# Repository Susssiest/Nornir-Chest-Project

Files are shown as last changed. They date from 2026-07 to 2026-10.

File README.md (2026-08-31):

# Nornir Chest from God of War Ragnarök

Whole Project

This is a 3D printable replica model of the Nornir Chest from God of War Ragnarök. My final version uses a variety of electronics to simulate the way the chest works in the game. In God Of War, Nornir Chests are puzzles found throughout the map that use their environments to hide and disguise the activators, or seals. There are 4 types of seals, totem poles, braziers, bells, and viking statues. They each have different activation methods, and each are tied to different runes on the chest. When a seal is activated, the rune on it flashes and disappears, and the corrisponding rune on the chest does the same. I currently have two versions of the chest, a fully printable version, and a fully electronic version with seals.

## The Seals

**Brazier** - two 7 pixel WS2812B rings, reed switch. Printed gold, black, grey, and blue/transparent PLA. Uses the reed switch to detect the magnetic Blades of Chaos inserted into the coals, and the LED rings are used as a rune and embers in the fire. The coals are printed with low infill and fewer walls so light can shine through. 

**Totem Pole** - 3 dumb LEDs, rotary encoder. Printed in PLA wood, and blue/transparent PLA. The rotary encoder tracks the rotation of the pole. The pole is connected to a hollow cylinder with three different runes. As it rotates, three LEDs on the side of the pole light the correct rune.

**Bell** - 1 dumb LED, piezo switch. Printed in PLA wood, gold, and blue/transperent PLA. The piezo disk detects vibration when the bell is rung. A dedicated LED lights the rune.

## The Chest

The chest uses three 7 pixel WS2812B rings and a servo. The servos turn 90 degrees to lock/unlock the chest, and the LEDs cover the runes. It is hinged, and is printed in multiple parts to avoid changes between the gold, black, grey, and blue/transparent PLA. Any parts that would otherwise be glued are connected via pins.

## The Base

The rocky base is not only a cool base for the chest, it acts as a hub for the electronics. I made room for a breadboard for beginners (like me lol), an Arduino Nano, and a battery pack. All wires go through holes, and they will have some supports in them when you pull them out. I suggest using a paper clip to stick it in and push all of the supports out, it shouldn't be too hard.

## Printing

The chest uses 5 filaments, mostly Sunlu and Bambu Labs. I printed some parts with a 0.2 mm nozzle, such as the hinges, viking head, runes, etc, to preserve small details and improve the accuracy of the prints. I also changed the speed and infill on some parts, for example, the runes are printed in 100% infill grey to let light only through the rune hole, and not be visible through the plastic. I always used glue, and I used a cheap smooth PEI plate I found on amazon.

643023963-7ee1bbd4-a273-487c-8561-48d0f8c64b1f

### All Components 

- Arduino Nano (powered via USB-C)
- 4× WS2812B LED rings (7 LEDs each) – one in each chest rune slot, and 2 in brazier
- 2× Servos – lock the lid
- Rotary encoder – rotating totem
- Reed switch – brazier (detects magnetic Blades of Chaos)
- Piezo disk – tracks bell vibration
- 3× single LEDs – illuminate the runes on the totem
- 1× single LED – illuminates the rune on the bell
- 4× AA battery pack – powers all LEDs and servos

## Credits

- [Blades of Chaos fridge magnet](https://makerworld.com/en/models/3068479-blades-of-chaos-fridge-magnet#profileId-3454054) — Used as the magnetic Blades of Chaos inserted into the brazier. It is meant to be a fridge magnet.
- [Stone formation base](https://makerworld.com/en/models/2541501-stoneformation-15?from=search#profileId-2798135) — This is the rocky base I used. I modified it to have a central port for all the electronics and indents to connect the chest and three seals.
- [HW-040 module case housing enclosure](https://makerworld.com/en/models/1896813-hw-040-module-case-housing-enclosure?from=search#profileId-2032305) — This is the enclosure I used for the rotary encoder.
- [Print-in-PLAce hinge set](https://makerworld.com/en/models/791901-print-in-PLAce-hinge-set?from=search#profileId-730453) — This is the hinge I used. I modified it to have extruded pins and be much smaller.

## Updates

- Added a fully 3D-printable version.
- Will update firmware to fit physical chest wherever needed.

## Get .blend File Here
(I'm also a noob to github lol. I can't figure out how to upload large files.)

https://drive.google.com/file/d/1p0lWug-2twfeMgqFWuvS9LOxBlz-mlpI/view?usp=sharing

## Updated BOM

Screenshot 2026-08-14 at 5 10 53 PM

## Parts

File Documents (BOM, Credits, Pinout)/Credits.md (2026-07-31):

https://makerworld.com/en/models/3068479-blades-of-chaos-fridge-magnet#profileId-3454054
https://makerworld.com/en/models/2541501-stoneformation-15?from=search#profileId-2798135
https://makerworld.com/en/models/1896813-hw-040-module-case-housing-enclosure?from=search#profileId-2032305
https://makerworld.com/en/models/791901-print-in-place-hinge-set?from=search#profileId-730453

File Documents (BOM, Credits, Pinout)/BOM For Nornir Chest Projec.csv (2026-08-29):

Item | Part Number | Description | Quantity (PART) | LINK | Notes | Prices | Total
1 | WS2812B-7-Ring | LED Ring | 5 | https://www.amazon.com/WS2812B-Integrated-Raspberry-Polarity-Protection/dp/B0FGNKC7QQ | 7 Pixel Each Ring. | $12 | $83.50
2 | A000005 | Arduino Nano Microcontroller | 1 | https://www.aliexpress.us/item/3256809685516678.html?curPageLogUid=5CaHrG3ZhrdQ |  | $13
2 | 59065-1-T-02-A | Reed Switch | 10 | https://www.aliexpress.us/item/3256803956030642.html?curPageLogUid=Fa0oPe1vlgEd |  | $2
3 | MG90D | Servo | 5 | https://www.aliexpress.us/item/2255800716939287.html?curPageLogUid=Z3gKo8SFpI16 | 4 pieces option. | $6
4 | KY040 | Rotary Encoder | 3 | https://www.aliexpress.us/item/3256812271134656.html?curPageLogUid=7Kls8qCOYRya | KY040 option. | $2.50
5 | 7BB-27-4L0 | Piezo Disk Sensor | 5 | https://www.aliexpress.us/item/3256805787073974.html?curPageLogUid=UOmzm5xA3pMd | 15 mm option. | $2
6 | N/A | Dupont Wires | N/P | https://www.aliexpress.us/item/3256806568245944.html?curPageLogUid=wJJyPuHxCR1f | 20 cm version. | $5.50
7 | MB102 | Breadboard | 1 | https://www.aliexpress.us/item/3256811972226710.html?curPageLogUid=qMl6iwuxHHIW | Need single 830 specifically. | $1.50
8 | D4X2MM | Magnet. 4 * 2 mm | N/A | https://www.aliexpress.us/item/3256809888929805.html?curPageLogUid=4x1vSrh0W456 |  | $6.50
9 | BH3411 | 4X AA Battery Holder | 2 | https://www.aliexpress.us/item/3256812462544992.html?curPageLogUid=n0huZEXnUeKT | 4X specifically. | $5
10 | L-7113QWC-D | 5mm White LED Diffused | 2 | https://www.aliexpress.us/item/3256809511151659.html?curPageLogUid=VWfludxQW9P6 | Need white option. | $4.50
11 | BJ-1OHM-1M-OHM | Resistor Kit | N/P | https://www.aliexpress.us/item/3256811586219421.html?curPageLogUid=IHU8X6zPDTQ3 | One kit. | $6.50
12 | N/A | Grey Filament | 1 | amazon.com/Filament-Printer-Beginner-Friendly-Printing/dp/B0DSC31ZXD/ref=sr_1_5_sspa?crid=2LGGIC794LPAT&dib=eyJ2IjoiMSJ9.eQKZI1h0T-YOPtObhboWIG_RNktaH_b-Udad5mX24wETbbpMUZ0Z5rh0vpbh7rLSgEg74xWm6uLPm_tvbGXEeIPvTcr38zwNHxsZ0UfXm-5ssqrQTWvOXREL1hwJ3alvJFGURizV0MXGbAhyBEPxa8I0v3zYT4xV4xi6m-6oXPM5TpVuQRroFNL9HL_fHbDlJ9-K2ohU5GUG8rBIKBY_ql5ROyeisAdPtTaoMvq7F6o.t3D__7Jmp2Mq9nTA0LAzR9pZMdfqqCc6r-YQqvCba5g&dib_tag=se&keywords=grey+sunlu&qid=1786670732&sprefix=gr+sunlu%2Caps%2C349&sr=8-5-spons&sp_csd=d2lkZ2V0TmFtZT1zcF9tdGY&psc=1 | Need specific light grey color. | $16
 |  |  |  | NOTE: Some links do not include full quantity in one purchase. | NOTE: This is my first electronics project, so I need a lot of different parts that an experienced hobbiest would have already. This means electronics like jumper wires, breadboards, resistors, etc, are things that I need because I am new to using electronics and don't have any myself.

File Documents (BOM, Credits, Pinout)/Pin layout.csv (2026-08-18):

Nano Pin | Part | Component
D2 | Totem LED 1 | Rotating Totem
D3 | Totem LED 2 | Rotating Totem
D4 | Totem LED 3 | Rotating Totem
D5 | WS2812B LED Ring | Brazier
D6 | 3× WS2812B LED Rings | Chest
D7 | Rotary Encoder CLK | Rotating Totem
D8 | Rotary Encoder DT | Rotating Totem
D9 | Servo Left | Chest Lock
D10 | Servo Right | Chest Lock
D11 | Rotary Encoder SW (optional) | Rotating Totem
D12 | Reed Switch | Brazier
D13 | Bell LED | Bell
A0 | Piezo Disk | Bell

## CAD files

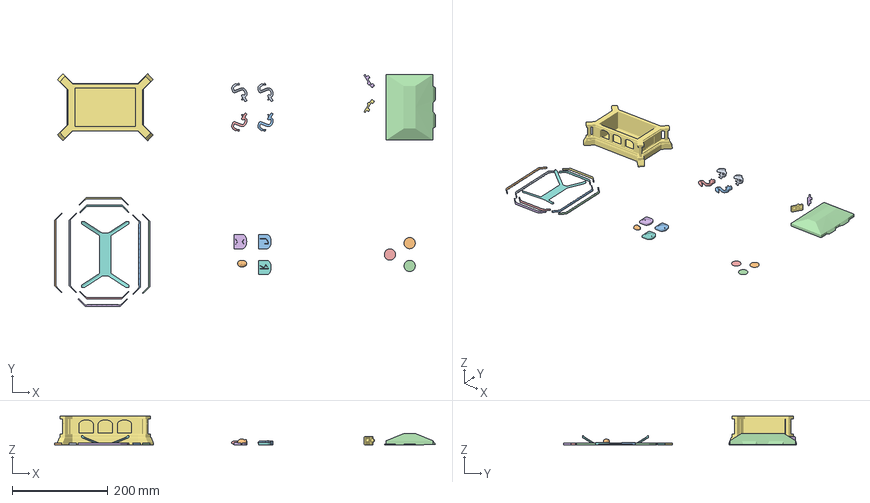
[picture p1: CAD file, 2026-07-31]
All CAD/Nornir Chest - Full 3D Print.3mf
794.8 x 485.2 x 60.0 mm
Corner_1.stl
Led_Cover_(C).stl
Rune_(N).stl
Led_Cover_(N).stl
Led_Cover_(R).stl
Rune_(C).stl
Main_Chest.stl
Rune_(R).stl
Corner_3.stl
Viking_Head.stl
Corner_2.stl
Lid.stl
Corner_4.stl
HINGE_1.stl
HINGE_2.stl
Gold_Engraving_(Lid).stl
Gold_Engraving_Long_1.stl
Gold_Engraving_Long_2.stl
Gold_Engraving_Long_3.stl
Gold_Engraving_Long_4.stl
Gold_Engraving_Short_1.stl
Gold_Engraving_Short_2.stl
Gold_Engraving_Short_3.stl
Gold_Engraving_Short_4.stl

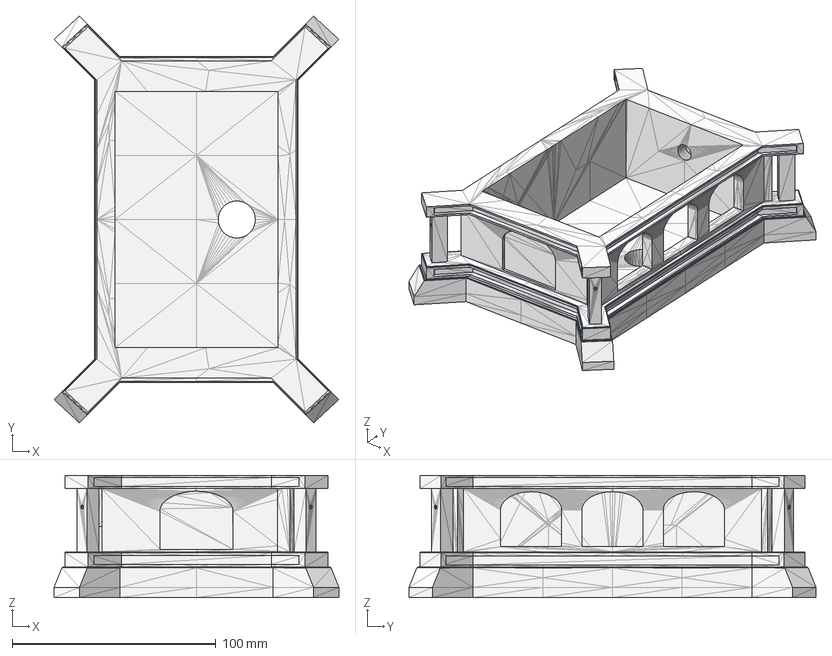
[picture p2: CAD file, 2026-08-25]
All CAD/All STEPS/Main_Chest - Arduino.step
140.0 x 200.0 x 60.0 mm

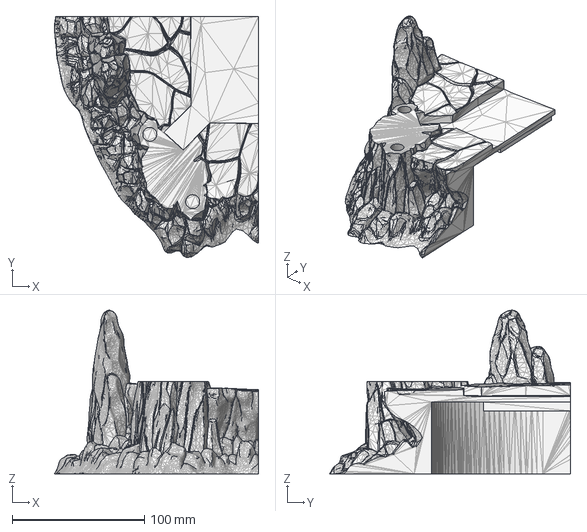
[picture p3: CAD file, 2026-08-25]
All CAD/All STEPS/Base_3.step
154.4 x 182.3 x 123.8 mm

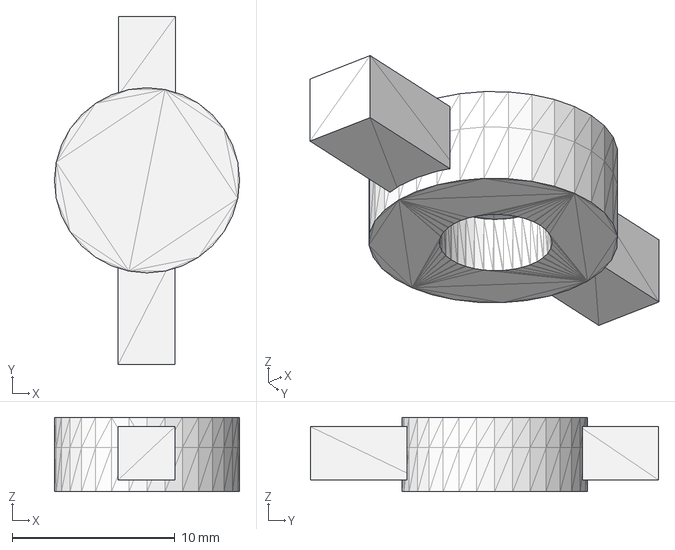
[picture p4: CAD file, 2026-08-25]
All CAD/All STEPS/Lock_2.step
11.4 x 21.4 x 4.58 mm

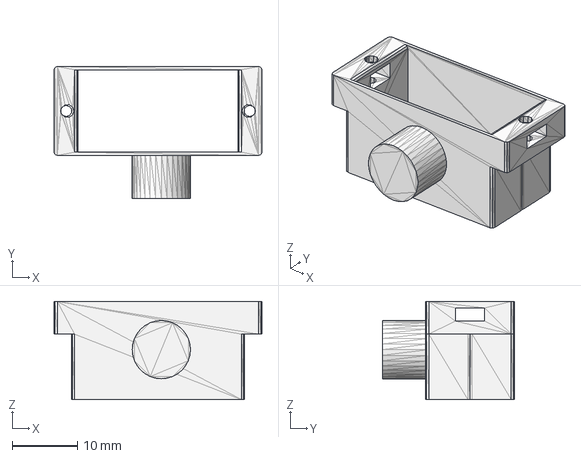
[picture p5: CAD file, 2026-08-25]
All CAD/All STEPS/Servo_Holder.step
31.8 x 20.2 x 15.0 mm

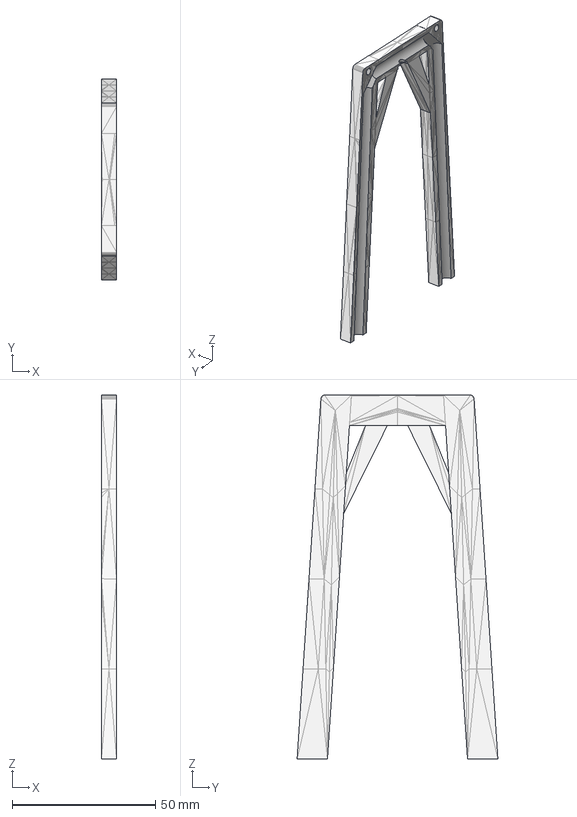
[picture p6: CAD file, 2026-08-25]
All CAD/All STEPS/Stand_1.step
5.31 x 70.1 x 127.0 mm

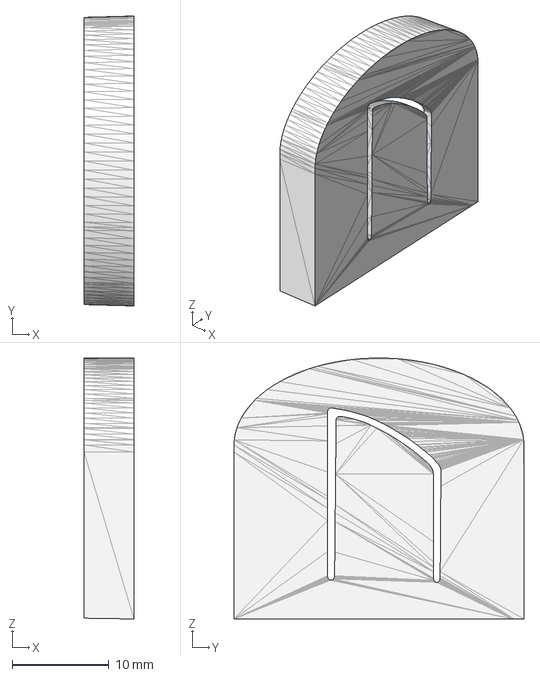
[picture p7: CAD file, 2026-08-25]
All CAD/All STEPS/Rune_(N).step
5.16 x 30.0 x 27.0 mm

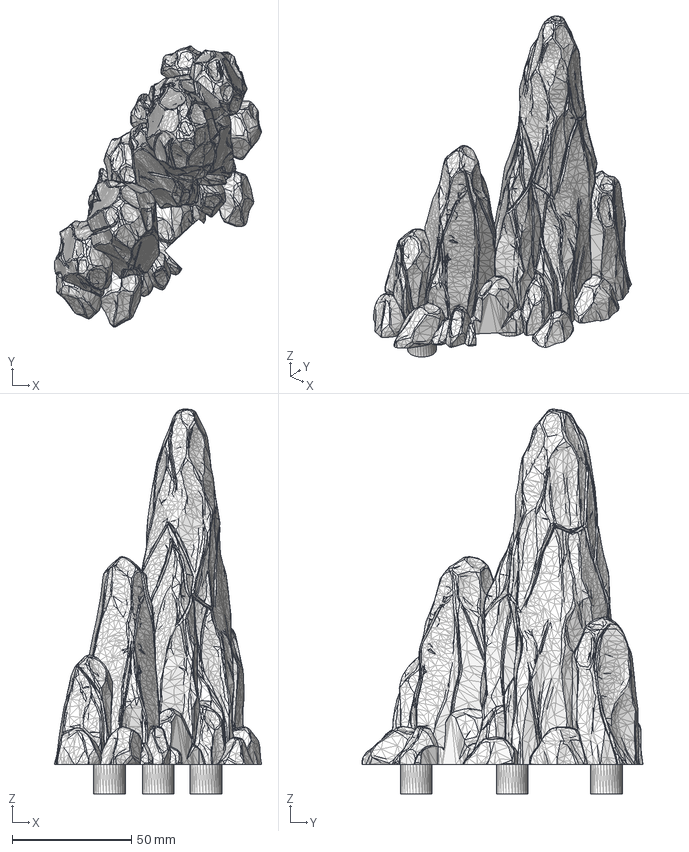
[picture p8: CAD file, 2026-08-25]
All CAD/All STEPS/Stalagmite_1.step
86.8 x 117.6 x 161.2 mm

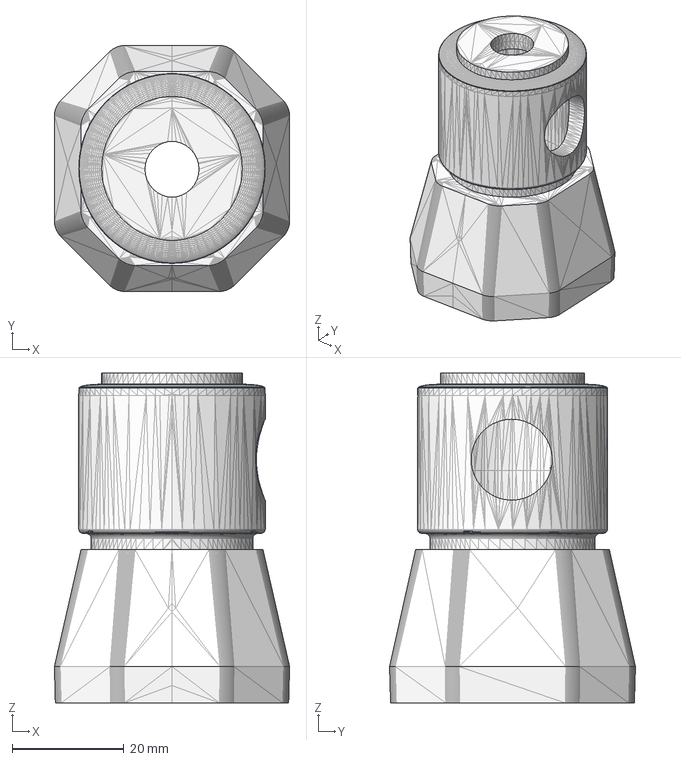
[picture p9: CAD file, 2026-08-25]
All CAD/All STEPS/Totem_Base.step
42.1 x 44.0 x 59.0 mm

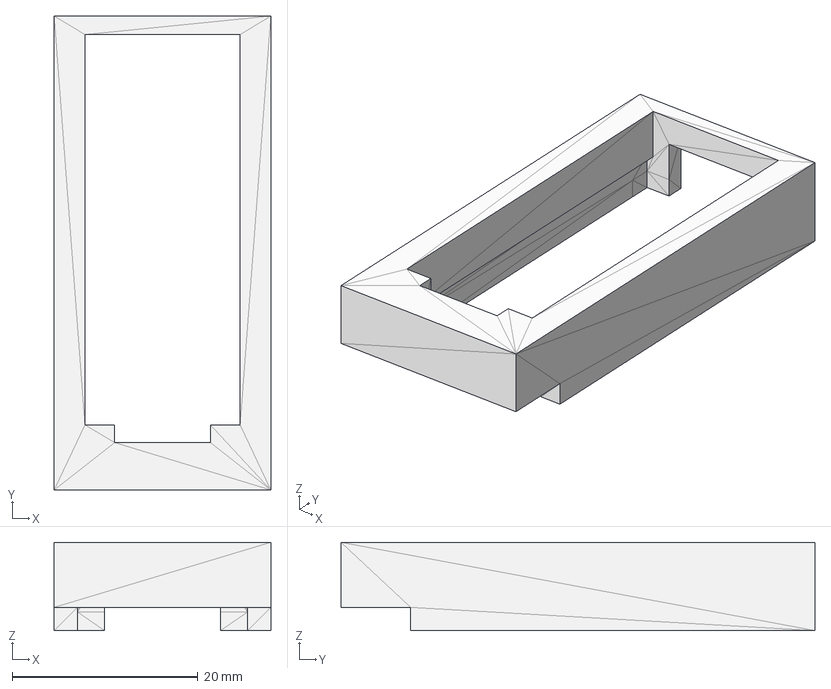
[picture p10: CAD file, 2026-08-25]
All CAD/All STEPS/Nano_Holder.step
23.3 x 51.0 x 9.51 mm

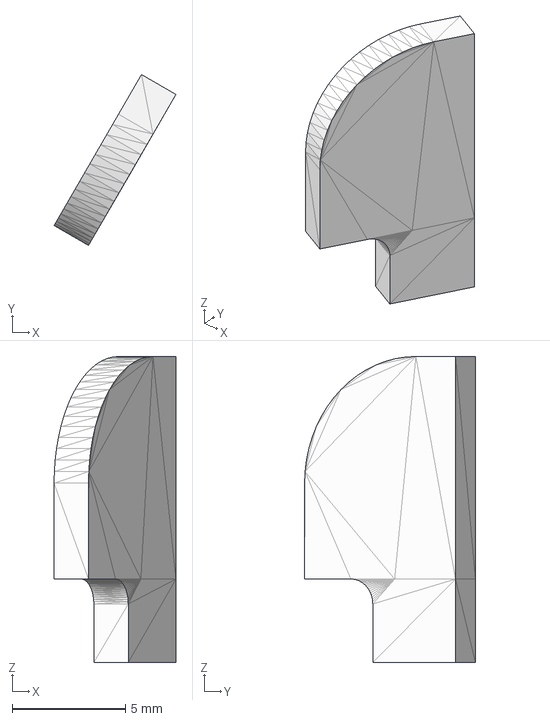
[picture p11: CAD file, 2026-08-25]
All CAD/All STEPS/Fin_PRINT_3.step
5.38 x 7.54 x 13.5 mm

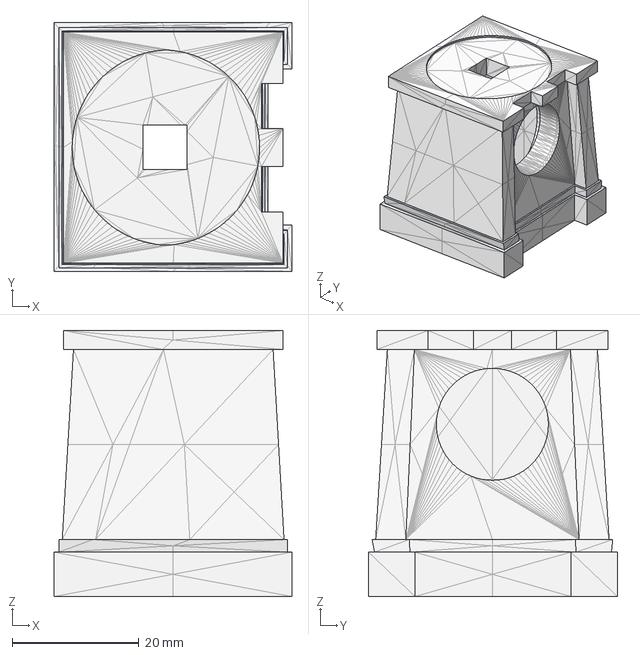
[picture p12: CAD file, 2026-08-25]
All CAD/All STEPS/Brazier_Base.step
37.5 x 39.3 x 42.0 mm

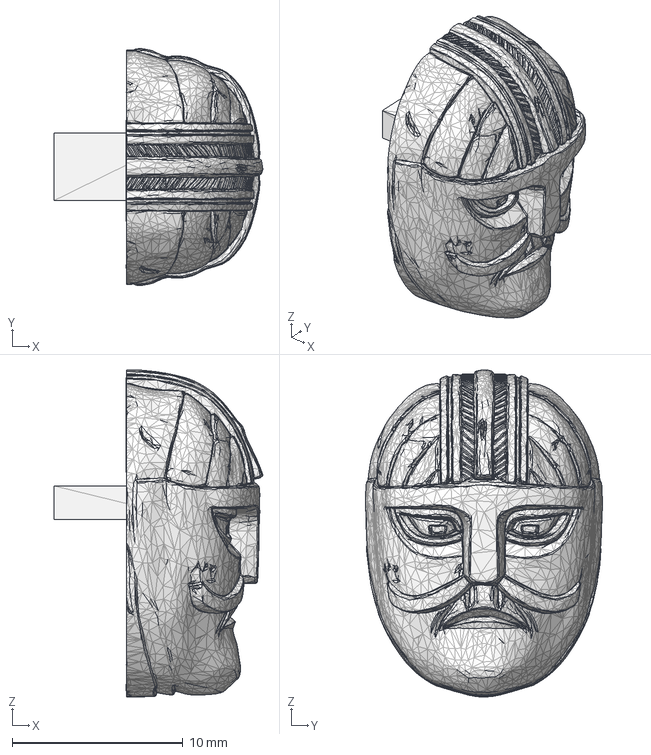
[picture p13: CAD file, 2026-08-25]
All CAD/All STEPS/Viking_Head.step
12.3 x 13.9 x 19.2 mm

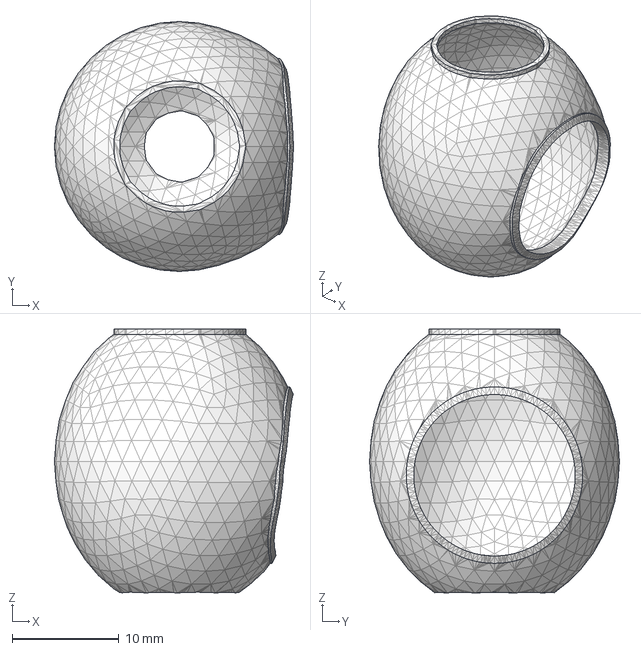
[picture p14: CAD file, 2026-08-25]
All CAD/All STEPS/Bell_Base.step
22.4 x 23.5 x 24.8 mm

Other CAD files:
All CAD/All STEPS/Servo_Holder_2.step
All CAD/All STEPS/Lock_1.step
All CAD/All STEPS/Stalagmite_2.step
All CAD/All STEPS/Rune_Cylinder.step
All CAD/All STEPS/Base_4.step
All CAD/All STEPS/Base_Cover.step
All CAD/All STEPS/Bell_Rune_(N).step
All CAD/All STEPS/Bell_Support.step
All CAD/All STEPS/Bottom.step
All CAD/All STEPS/Brazier_Rune_(R).step
All CAD/All STEPS/Brazier_Rune_Cover.step
All CAD/All STEPS/Electronics_Cover.step
All CAD/All STEPS/Gold_Engraving_(Lid).step
All CAD/All STEPS/Gold_Engraving_Long PRINT_4.step
All CAD/All STEPS/Hing_PRINT_2.step
All CAD/All STEPS/LED_Cover_(Totem_Pole).step
All CAD/All STEPS/Led_Cover_Print_3.step
All CAD/All STEPS/Lid.step
All CAD/All STEPS/Pole_Target Print_3.step
All CAD/All STEPS/Ring_Print_3.step
All CAD/All STEPS/Rune_(C).step
All CAD/All STEPS/Rune_(R).step
All CAD/All STEPS/Stand_Pin.step
All CAD/All STEPS/Totem_Pole.step

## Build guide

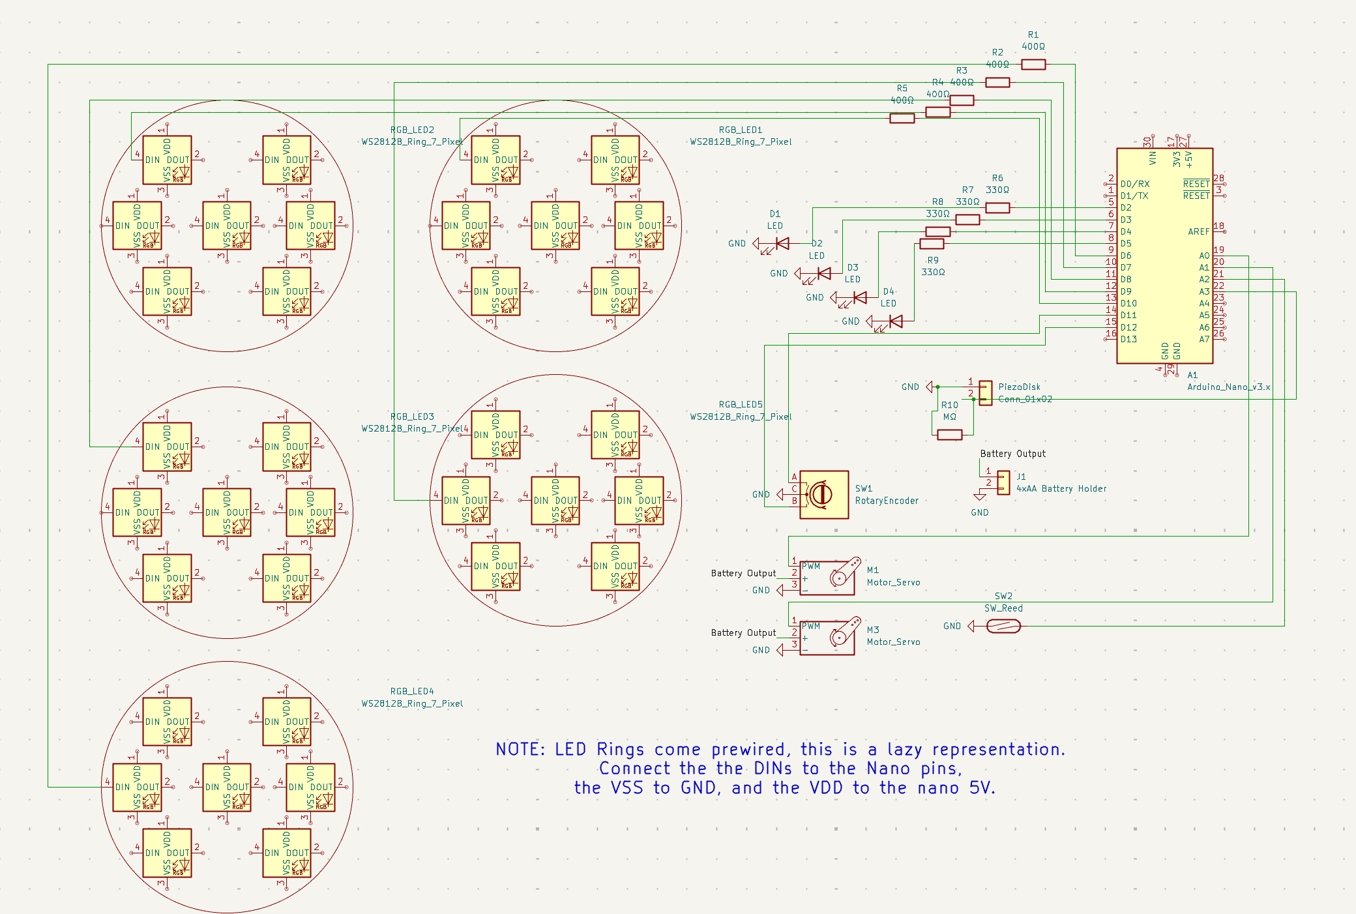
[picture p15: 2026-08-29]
Wiring Diagram.png

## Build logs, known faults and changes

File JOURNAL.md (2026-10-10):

# Journal

**PLEASE NOTE:**

- Project was moved from stardance to forge.
- I can't find actual dates I worked on projects, lapse gives me an estimate, like "3 months ago." for some reason, pretty annoying. The dates are estimations.
- This project was moved from stardance to forge, and the journals are just copied and pasted devlogs with some added details here and there.
- This was stardance, and I was a noob, so my devlogs are super short, and I switched between working on lots of different aspects of project, so I might log 2 hours 40 minutes and work for 40 minutes on the main thing and go over it in devlog, but spend another 2 hours polishing up a bunch of other stuff.
- I worked on this 3 months ago, I barely remember my workflow, I've tried to add a little more details, but pls be forgiving on awful devlogs.

## Worked on basic CAD on shell.

Started building my 3d printable Nornir Chest from God Of War. Just basic cadding, adding details like bevels, electronic holes, and runes later. Only cadded base chest, haven't started on lid or like hinges yet.



**Total time spent: 1h 25m**

## Worked on dragon corners 

Spent forever working on dragon corners, many revisions, restarted multiple times. Tried using cylinders, didn't work, tried using curves, kinda worked, eventually settled on a really low poly model because it prints tiny.



**Total time spent: 8h 32m**

## Added hinges and engravings

Added hinges and a gold engraving on the top of the lid. Looks great, moving on to head and leds for runes. Hinges print seperately and are inserted into pin holes, and are print in place, going to use 0.2mm nozzle because of how small they are. Gold engraving fits on the top and also is printed seperately.



**Total time spent: 1h 10m **

## Runes

Added runes! Looks great. Going to be using WS2812B Led rings, and I’m going to 3d print a cover thing for it that will disperse the lighting as it only has 7 leds per ring. 3 different runes, inserted into 3 different holes in chest.



**Total time spent: 2h 59m**

## Made MG90 Locking mechanism

It locks now! Will be using mg90 servos that turn 90 degrees, making the lid unable to open. Lid will have two holes on either sides with small covers that allow servo arm to fly over, but get stuck when lifted, because servo arm is in its way.



**Total time spent: 1h 47m**
 
## New gold engraving

Added a new gold engraving. It has kind of a loopy pattern, spent forever using curves to get it right, fits into holes in chest. Used multiple tutorials and I think I redid it maybe 4 times.



**Total time spent: 1h 31m**

## Made boulder and then gave up.

Spent some time making a boulder for the seals to sit on, but then I kind of gave up and realized it was ugly lol.



**Total time spent: 2h 47m**

## Chest base

The chest has a base now! The base is so big it has to split into fourths to fit on the printer bed 😂. It is ~700 grams. I also added indents in it that will fit a breadboard, battery pack, and wires. I’m going to be using a nano on the breadboard. I could just stuff all the electronics in the chest, but then i wouldnt be able to fir anything inside, so I’m just doing this. I also think it looks awesome and I need to add some of the puzzles that unlock the chest around it, so the base is perfect. Got the base off of makerworld - https://makerworld.com/en/models/2679972-rocky-base-plateau#profileId-2967898



**Total time spent: 4h 12m**
 
## Worked on brazier

I’m adding a little brazier with a led rune that will turn off when activated, and send a signal to the chest to also turn off one of the lights. Once three runes are activated the chest’s servos will activate and it will be able to open. Almost done with brazier, need to add some more coal on the top.



**Total time spent: 2.16 hours**
 
## Added reed switch

Added reed switch to brazier, I downloaded a nice blades of chaos fridge magnet, that can be inserted into the top. So hopefully when the magnetic blade gets inserted the reed switch will activate and send a signal to the arduino.



**Total time spent: 52m**
 
## CHose new base.

I’m choosing to use a different base, it just looks cooler, and also the other base had all these random strings of internal vertices. Also worked a little on the spinning rune activator/totem.



**Total time spent: 3h 38m**
 
## Finished brazier and totem.

Done with both brazier and spinning totem! On to rune rock and then wire paths and electronics.



**Total time spent: 46m**
 
## Finished everything.

Done with everything! I decided to do the bell instead of rune rock because I realized it wasn’t actually a rock, it was a statue, and I don’t want to spend 2 hours sculpting it. Prepping it in bambu studio, almost ready to start printing! Attached photo of statue to show you what I mean.



**Total time spent: 8h 30m**
 
## test print.

Printed base, supports are way to crazy and areas are too weak, tweaking and reprinting. Also starting to add some more work to the bambu studio portion of the project.



**Total time spent: 1h 13m**
 
## August 7th

Almost done with Bambu Studio. Putting together files for a fully 3d printable model too, no electronics, no base.



**Total time spent: 25m**
 
## Submitted for funding.

I’m submitting this for funding! I am broke and cant pay for the electronics lol. I also printed out a few parts. It needs a little post prosessing but looks great!

Screenshot 2026-09-15 at 4 40 39 PM

**Total time spent: 17m**
 
## Printed everything.

Finally printed all of the print only parts! Looks awesome. Still waiting on electronics.



**Total time spent: 19m**
 
## Posted on makerworld

Worked on firmware and updated BOM. also posted on makerworld! https://makerworld.com/en/models/3198743-god-of-war-nornir-chest-hinged-lid-no-ams#profileId-3619555



**Total time spent: 1h 4m**
 
## New lamp version.

Made a cheap lamp version using a kit from bambu labs, posted on makerworld. https://makerworld.com/en/models/3271930-god-of-war-nornir-chest-lamp-edition#profileId-3710162

Screenshot 2026-09-15 at 5 11 46 PM

**Total time spent: 1h 16m**

## Parts came

All parts came! Spent 2 minutes pulling in package i guess lol. Gonna start working on final build.

Screenshot 2026-09-15 at 5 18 21 PM

**Total time spent: 2m**

## More printing

Printed and removed all supports of 1/4 of the base. My stupid ass didn't record the first 5 minutes of support removal, and in the three visible frames I'm holding the base out of the cameras line of sight.

Screenshot 2026-09-16 at 4 24 35 PM

**Total time spent: 10m**

## Started working on arduino

Soldered on pin headers to the nano, dupont connectors to the battery holder, and looped all the leds.

Screenshot 2026-09-21 at 6 56 41 PM

**Total time spent: 1h 2m**

## Chest leds

Connected LEDs to nano, they work great. I'm really happy with how they came out. I'm going to work out the firmware to make it glow/ flicker blue. Also temporarily duct taped everything. I have settled on soldering everything together after I am out of the prototyping phase.

Screenshot 2026-09-22 at 10 12 33 AM

**Total time spent: 30 m**

## Servos dont fit in lid.

Tested servos, current lid locking system is really bad, servo arm doesnt even fit in the space I made for it. Changed lid to have an extruding handle thing that will be blocked by servo arms. 

Screenshot 2026-10-04 at 5 19 23 PM

**Total time spent: 1 hour**

## Fixed servos, work good.

Printed out new parts, replaced them, and tested. I had a pretty easy time printing everything, took out old servo holders and added new ones. The lid did kind of lock, but I was able to lift the lid up maybe two centimeters. Decreased the tolerance in the lid handle things by wrapping duct tape around it. Added switch to open and close servos and uploaded new testing code. It works! I'm actually really happy with how it came out! Will start testing brazier tommorow.

Pi7_GIF_CMP-ezgif com-crop

**Total time spent: 2 hour**

## Totem pole leds

Spent like 3 hours trying to solder wire to a tiny led strip. Accidentally bought 2.5mm instead of 5mm. I wasted like 30 mm of wire. The strip has an adhesive on the bottom that prevents solder to sticking on pads so I ended up just covering the led strip with burnt glue and solder without actually making any connections. The diode leds i ordered dont work as well, they all came with messed up internals, I can see the metal parts inside are way too close togther.

Screenshot 2026-10-03 at 9 10 33 AM

**Total time spent: 3 hours**

## More work on totem pole leds

I took a portion of a bigger led strip from school because the one I own is way too hard to solder. I accidentally soldered the wires onto the DOUT side, and after 40 minutes of playing with arduino ide and switching between micrcontrollers, I finally decided to check the soldering a little closer, and realized I had soldered it on wrong. So I soldered it on correctly, and tested the leds, and they worked. Then I stuffed it into the pole and broke it accidentally. And then I decided to just gave up for the day for some reason.

Screenshot 2026-10-03 at 9 11 07 AM

**Total time spent: 2 hours**

## Finally got leds to work.

Soldered everything corectly this time, took maybe 30 minutes including setup and putting everything away. Made basic firmware to test if the rotary encoders work, and they do, it looks great. Spent forever trying to protect the wires against touching using tape, and connecting the rotary encoder to the breadboard, but it works! Leds flash red when not correct rune, leds flash white when correct. For some reason the leds stopped working and then after 30 minutes of panicking hey started working again, so I guess they work?

Screenshot 2026-10-04 at 4 39 45 PM

**Total time spent: 4 hours**

## Uh, i want to keep my forge streak.

I'm logging the five minutes it took to setup my printer and send a print because I want to keep my forge streak. Yeah.

Screenshot 2026-10-05 at 12 59 30 PM

**Total time spent: 5 minutes**

## Broke the last 3 led rings while soldering.

I spent over three hours trying to solder the wires pointing up horizontally, and ended up breaking every LED. The first leds pad fell off, the second ones' whole vcc trace and pad fell off, and the last led looked soldered ok, but when I plugged it into the nano it started smoking for some reason, so I took it out, and now the nano doesn't work. Luckily I bought a second one, so I had to replace it and solder all the pins on. I'm going to try to fix the last led, but worst case scenario I'll just use a cut off portion from a led strip.

**Total time spent: 4 hours**

## Soldered the reed switch to some dupont pins.

Luckily soldering the reed switch wasn't too hard, tested with a led and it works great. Now I'm going to stop ignoring soldering the leds and do it.

Screenshot 2026-10-08 at 8 25 48 PM

**Total time spent: 40 minutes**

## Got the last LED ring to work somehow

I resoldered everything, and now it works! Tested it, moving on to code and implementation.

Screenshot 2026-10-08 at 8 24 05 PM

**Total time spent: 1 hour**

## Hooked up leds and reed switch to nano, it works!

Connected everything to dupont pins and then the nano, and coded the reed switch part, it works! Blinks like the totem when activated. I am experiencing a problem where the rotary encoder automatically thinks it is on F when starting, going to fix.

Screenshot 2026-10-09 at 7 35 35 PM

**Total time spent: 1 hour 20 minutes**

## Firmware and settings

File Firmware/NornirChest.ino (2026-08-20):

#include "arduino_secrets.h"

#include <Adafruit_NeoPixel.h>
#include <Servo.h>

// ============================================================
// Pin assignments
// ============================================================

const byte TOTEM_LED_1_PIN = 2;
const byte TOTEM_LED_2_PIN = 3;
const byte TOTEM_LED_3_PIN = 4;

const byte BRAZIER_RING_PIN = 5;
const byte CHEST_RINGS_PIN  = 6;

const byte ENCODER_CLK_PIN = 7;
const byte ENCODER_DT_PIN  = 8;

const byte LEFT_SERVO_PIN  = 9;
const byte RIGHT_SERVO_PIN = 10;

const byte REED_SWITCH_PIN = 12;
const byte BELL_LED_PIN    = 13;
const byte PIEZO_PIN       = A0;

// D11 is not used.
// The rotary encoder switch is intentionally disconnected.

// ============================================================
// LED settings
// ============================================================

const byte CHEST_RING_COUNT = 3;
const byte PIXELS_PER_RING = 7;
const byte CHEST_PIXEL_COUNT = CHEST_RING_COUNT * PIXELS_PER_RING;

// Set this to 7 if you have one brazier ring.
// Set it to 14 if two brazier rings are chained together.
const byte BRAZIER_PIXEL_COUNT = 14;

const byte LED_BRIGHTNESS = 80;

Adafruit_NeoPixel chestPixels(
  CHEST_PIXEL_COUNT,
  CHEST_RINGS_PIN,
  NEO_GRB + NEO_KHZ800
);

Adafruit_NeoPixel brazierPixels(
  BRAZIER_PIXEL_COUNT,
  BRAZIER_RING_PIN,
  NEO_GRB + NEO_KHZ800
);

// ============================================================
// Servo settings
// ============================================================

Servo leftServo;
Servo rightServo;

// Adjust these angles for your physical lock mechanism.
const int LEFT_LOCKED_ANGLE   = 20;
const int LEFT_UNLOCKED_ANGLE = 110;

const int RIGHT_LOCKED_ANGLE   = 160;
const int RIGHT_UNLOCKED_ANGLE = 70;

// ============================================================
// Rotary encoder settings
// ============================================================

// Change this if your encoder has a different number of detents.
const int ENCODER_DETENTS_PER_REVOLUTION = 20;

// The three rune positions around the totem.
const int RUNE_ANGLES[] = {
  0,
  120,
  240
};

const byte NUMBER_OF_RUNES = 3;

// A rune is accepted within 5 degrees of its target angle.
const int ANGLE_CLEARANCE = 5;

int lastCLKState = HIGH;
long encoderDetents = 0;
bool encoderHasMoved = false;

// ============================================================
// Bell settings
// ============================================================

const int PIEZO_THRESHOLD = 180;
const unsigned long BELL_COOLDOWN_MS = 700;

unsigned long lastBellTrigger = 0;

// ============================================================
// Game state
// ============================================================

bool brazierSolved = false;
bool bellSolved = false;
bool totemSolved = false;
bool chestUnlocked = false;

// ============================================================
// Colors
// ============================================================

uint32_t lockedRuneColor;
uint32_t brazierActiveColor;
uint32_t flashColor;
uint32_t offColor;

// ============================================================
// Setup
// ============================================================

void setup() {
  Serial.begin(9600);

  // Ordinary LEDs
  pinMode(TOTEM_LED_1_PIN, OUTPUT);
  pinMode(TOTEM_LED_2_PIN, OUTPUT);
  pinMode(TOTEM_LED_3_PIN, OUTPUT);
  pinMode(BELL_LED_PIN, OUTPUT);

  // Rotary encoder
  pinMode(ENCODER_CLK_PIN, INPUT_PULLUP);
  pinMode(ENCODER_DT_PIN, INPUT_PULLUP);

  // Reed switch
  // The reed switch should connect D12 to GND when activated.
  pinMode(REED_SWITCH_PIN, INPUT_PULLUP);

  // Start encoder reading
  lastCLKState = digitalRead(ENCODER_CLK_PIN);

  // Initialize NeoPixels
  chestPixels.begin();
  brazierPixels.begin();

  chestPixels.setBrightness(LED_BRIGHTNESS);
  brazierPixels.setBrightness(LED_BRIGHTNESS);

  lockedRuneColor = chestPixels.Color(255, 70, 0);
  brazierActiveColor = brazierPixels.Color(255, 0, 0);
  flashColor = chestPixels.Color(255, 255, 255);
  offColor = chestPixels.Color(0, 0, 0);

  // Initialize servos
  leftServo.attach(LEFT_SERVO_PIN);
  rightServo.attach(RIGHT_SERVO_PIN);

  lockChest();

  clearBrazier();
  updateTotemLEDs(-1);
  updateChestRunes();

  Serial.println(F("Nornir Chest ready."));
  Serial.println(F("Solve the brazier, bell, and rotating totem."));
}

// ============================================================
// Main loop
// ============================================================

void loop() {
  if (chestUnlocked) {
    return;
  }

  checkBrazier();
  checkBell();
  checkTotem();

  if (brazierSolved && bellSolved && totemSolved) {
    unlockChest();
  }
}

// ============================================================
// Brazier
// ============================================================

void checkBrazier() {
  bool magnetDetected = digitalRead(REED_SWITCH_PIN) == LOW;

  if (magnetDetected && !brazierSolved) {
    brazierSolved = true;

    Serial.println(F("Brazier solved."));

    setAllBrazierPixels(brazierActiveColor);
    completeSeal(0);
  }
}

// ============================================================
// Bell
// ============================================================

void checkBell() {
  if (bellSolved) {
    return;
  }

  int piezoValue = analogRead(PIEZO_PIN);

  if (piezoValue >= PIEZO_THRESHOLD &&
      millis() - lastBellTrigger >= BELL_COOLDOWN_MS) {

    lastBellTrigger = millis();
    bellSolved = true;

    Serial.print(F("Bell solved. Piezo value: "));
    Serial.println(piezoValue);

    digitalWrite(BELL_LED_PIN, HIGH);
    completeSeal(1);
  }
}

// ============================================================
// Rotary encoder
// ============================================================

void checkTotem() {
  int currentCLKState = digitalRead(ENCODER_CLK_PIN);

  // Read one edge of the encoder's CLK signal.
  if (currentCLKState != lastCLKState && currentCLKState == LOW) {
    if (digitalRead(ENCODER_DT_PIN) != currentCLKState) {
      encoderDetents++;
    } else {
      encoderDetents--;
    }

    encoderDetents = wrapEncoderPosition(encoderDetents);
    encoderHasMoved = true;

    int currentAngle = getEncoderAngle();
    int selectedRune = findMatchingRune(currentAngle);

    Serial.print(F("Totem angle: "));
    Serial.print(currentAngle);
    Serial.print(F(" degrees, selected rune: "));
    Serial.println(selectedRune);

    updateTotemLEDs(selectedRune);

    // Require the user to rotate the totem at least once.
    // This prevents the chest from solving immediately at startup.
    if (encoderHasMoved && selectedRune >= 0 && !totemSolved) {
      totemSolved = true;

      Serial.println(F("Totem solved."));
      completeSeal(2);
    }
  }

  lastCLKState = currentCLKState;
}

long wrapEncoderPosition(long position) {
  while (position >= ENCODER_DETENTS_PER_REVOLUTION) {
    position -= ENCODER_DETENTS_PER_REVOLUTION;
  }

  while (position < 0) {
    position += ENCODER_DETENTS_PER_REVOLUTION;
  }

  return position;
}

int getEncoderAngle() {
  long angle = encoderDetents * 360L;
  angle /= ENCODER_DETENTS_PER_REVOLUTION;

  return angle;
}

int getAngleDifference(int firstAngle, int secondAngle) {
  int difference = abs(firstAngle - secondAngle);

  // Correctly handles the wraparound between 359 and 0 degrees.
  if (difference > 180) {
    difference = 360 - difference;
  }

  return difference;
}

int findMatchingRune(int currentAngle) {
  for (byte i = 0; i < NUMBER_OF_RUNES; i++) {
    int difference = getAngleDifference(
      currentAngle,
      RUNE_ANGLES[i]
    );

    if (difference <= ANGLE_CLEARANCE) {
      return i;
    }
  }

  return -1;
}

void updateTotemLEDs(int selectedRune) {
  digitalWrite(
    TOTEM_LED_1_PIN,
    selectedRune == 0 ? HIGH : LOW
  );

  digitalWrite(
    TOTEM_LED_2_PIN,
    selectedRune == 1 ? HIGH : LOW
  );

  digitalWrite(
    TOTEM_LED_3_PIN,
    selectedRune == 2 ? HIGH : LOW
  );
}

// ============================================================
// Chest rune LEDs
// ============================================================

void updateChestRunes() {
  setChestRing(
    0,
    brazierSolved ? offColor : lockedRuneColor
  );

  setChestRing(
    1,
    bellSolved ? offColor : lockedRuneColor
  );

  setChestRing(
    2,
    totemSolved ? offColor : lockedRuneColor
  );

  chestPixels.show();
}

void setChestRing(byte ringNumber, uint32_t color) {
  int firstPixel = ringNumber * PIXELS_PER_RING;

  for (byte i = 0; i < PIXELS_PER_RING; i++) {
    chestPixels.setPixelColor(firstPixel + i, color);
  }
}

void flashChestRing(
  byte ringNumber,
  byte numberOfFlashes,
  int delayTime
) {
  for (byte flash = 0; flash < numberOfFlashes; flash++) {
    setChestRing(ringNumber, flashColor);
    chestPixels.show();
    delay(delayTime);

    setChestRing(ringNumber, offColor);
    chestPixels.show();
    delay(delayTime);
  }
}

void completeSeal(byte ringNumber) {
  flashChestRing(ringNumber, 3, 130);
  setChestRing(ringNumber, offColor);
  chestPixels.show();
}

// ============================================================
// Brazier LEDs
// ============================================================

void setAllBrazierPixels(uint32_t color) {
  for (byte i = 0; i < BRAZIER_PIXEL_COUNT; i++) {
    brazierPixels.setPixelColor(i, color);
  }

  brazierPixels.show();
}

void clearBrazier() {
  setAllBrazierPixels(offColor);
}

// ============================================================
// Servos and chest lock
// ============================================================

void lockChest() {
  leftServo.write(LEFT_LOCKED_ANGLE);
  rightServo.write(RIGHT_LOCKED_ANGLE);

  Serial.println(F("Chest locked."));
}

void unlockChest() {
  chestUnlocked = true;

  Serial.println(F("All seals solved."));
  Serial.println(F("Unlocking chest."));

  // Celebration flash
  for (byte flash = 0; flash < 3; flash++) {
    for (int i = 0; i < CHEST_PIXEL_COUNT; i++) {
      chestPixels.setPixelColor(i, flashColor);
    }

    chestPixels.show();
    delay(180);

    for (int i = 0; i < CHEST_PIXEL_COUNT; i++) {
      chestPixels.setPixelColor(i, offColor);
    }

    chestPixels.show();
    delay(180);
  }

  // Move the locks to the open position.
  leftServo.write(LEFT_UNLOCKED_ANGLE);
  rightServo.write(RIGHT_UNLOCKED_ANGLE);

  // Leave the brazier lit.
  setAllBrazierPixels(brazierActiveColor);

  // Leave all totem and bell LEDs lit.
  digitalWrite(TOTEM_LED_1_PIN, HIGH);
  digitalWrite(TOTEM_LED_2_PIN, HIGH);
  digitalWrite(TOTEM_LED_3_PIN, HIGH);
  digitalWrite(BELL_LED_PIN, HIGH);
}

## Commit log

2026-07-31 Rename Nornir Chest - Arduino.3mf to Chest - Arduino.3mf
    [Chest - Arduino.3mf]
2026-07-31 Rename Chest - Arduino.3mf to Nornir Chest - Arduino.3mf
    [Nornir Chest - Arduino.3mf]
2026-07-31 Rename All Chest (Arduino) STLs.zip to Chest - Arduino STLs.zip
2026-07-31 Update README with new 3D printable version
    Added a note about the fully 3D printable version of the model.
2026-07-31 Add new model link for print-in-place hinge set
2026-08-03 Enhance README with electronics details and updates
    Expanded the README to include details about the electronics used in the Nornir Chest project, including descriptions of the seals and components. Added credits for resources and an update about a fu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
2026-08-03 Add documentation for Nornir Chest project
    Added detailed documentation for the Nornir Chest project, including project overview, electronics, pin assignments, wiring diagram, and power connections.
2026-08-03 Rename Wiring Diagram.readme to Wiring Diagram.md
2026-08-03 Update Wiring Diagram.md
2026-08-03 Revise Piezo disk description and add LED details
    Updated the description of the Piezo disk and added details about an additional LED ring in the brazier.
2026-08-03 Revise wiring diagram and power connection details
    Updated wiring diagram with detailed component connections and power notes.
2026-08-14 Update README to remove note and add BOM section
    Removed note about hardware request reviewer and added BOM section with an image.
2026-08-14 Add screenshot to BOM section in README
    Added a new screenshot to the BOM section of the README.
2026-08-14 Update BOM section in README
2026-08-18 Add link to pin layout CSV file in wiring diagram
2026-08-25 adding file
    [Base_3.step, Base_4.step, Base_Cover.step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]
2026-08-25 folder organization
    [BOM For Nornir Chest Projec.csv, Pin layout.csv]
2026-08-29 Rename Wiring Diagram.md to Electronics Overview.md
2026-08-29 Revise BOM to include prices and notes
    Updated BOM with prices and additional notes for each item.
    [BOM For Nornir Chest Projec.csv]
2026-08-31 Enhance README with detailed seal descriptions
    Expanded descriptions for the seals including functionality and materials used.
2026-08-31 Add components list to README
    Added a section detailing all components used in the project, including Arduino, LEDs, servos, and power supply.
2026-08-31 Add wiring diagram to Electronics Overview
    Added wiring diagram section to the project overview.
2026-10-04 Fix spelling and clarity in JOURNAL.md entry
    Corrected spelling errors and improved clarity in the journal entry about the rotary encoders and LEDs.
2026-10-09 Revise soldering incident in JOURNAL.md
    Updated the soldering incident description for clarity and detail.
2026-10-09 Update journal entry on reed switch soldering
    Added a note about testing the reed switch with a LED and mentioned plans to solder LEDs.
2026-10-09 Update JOURNAL.md with LED ring soldering details
    Documented the successful soldering of the last LED ring and included a screenshot.
2026-11-08 Update JOURNAL.md with soldering challenges
    Documented issues encountered while soldering LED rings and noted total time spent.
